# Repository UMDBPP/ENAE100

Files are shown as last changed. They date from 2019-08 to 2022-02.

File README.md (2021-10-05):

# ENAE100
This repository is for the starter shields used in the ENAE100 Freshman Workshops during the fall semester

# Dependencies
* [OneWire](https://github.com/PaulStoffregen/OneWire) by Paul Stoffregen
* [DallasTemperature](https://github.com/milesburton/Arduino-Temperature-Control-Library) by Miles Burton
* [RTClib](https://github.com/adafruit/RTClib) by Adafruit

# Contents
## /Board
Gerbers and board files

## /Code/StarterShield
Working sample code for the board

# Notes/FAQ
1. SD Chip Select is Pin 10
2. LED is on pin 9

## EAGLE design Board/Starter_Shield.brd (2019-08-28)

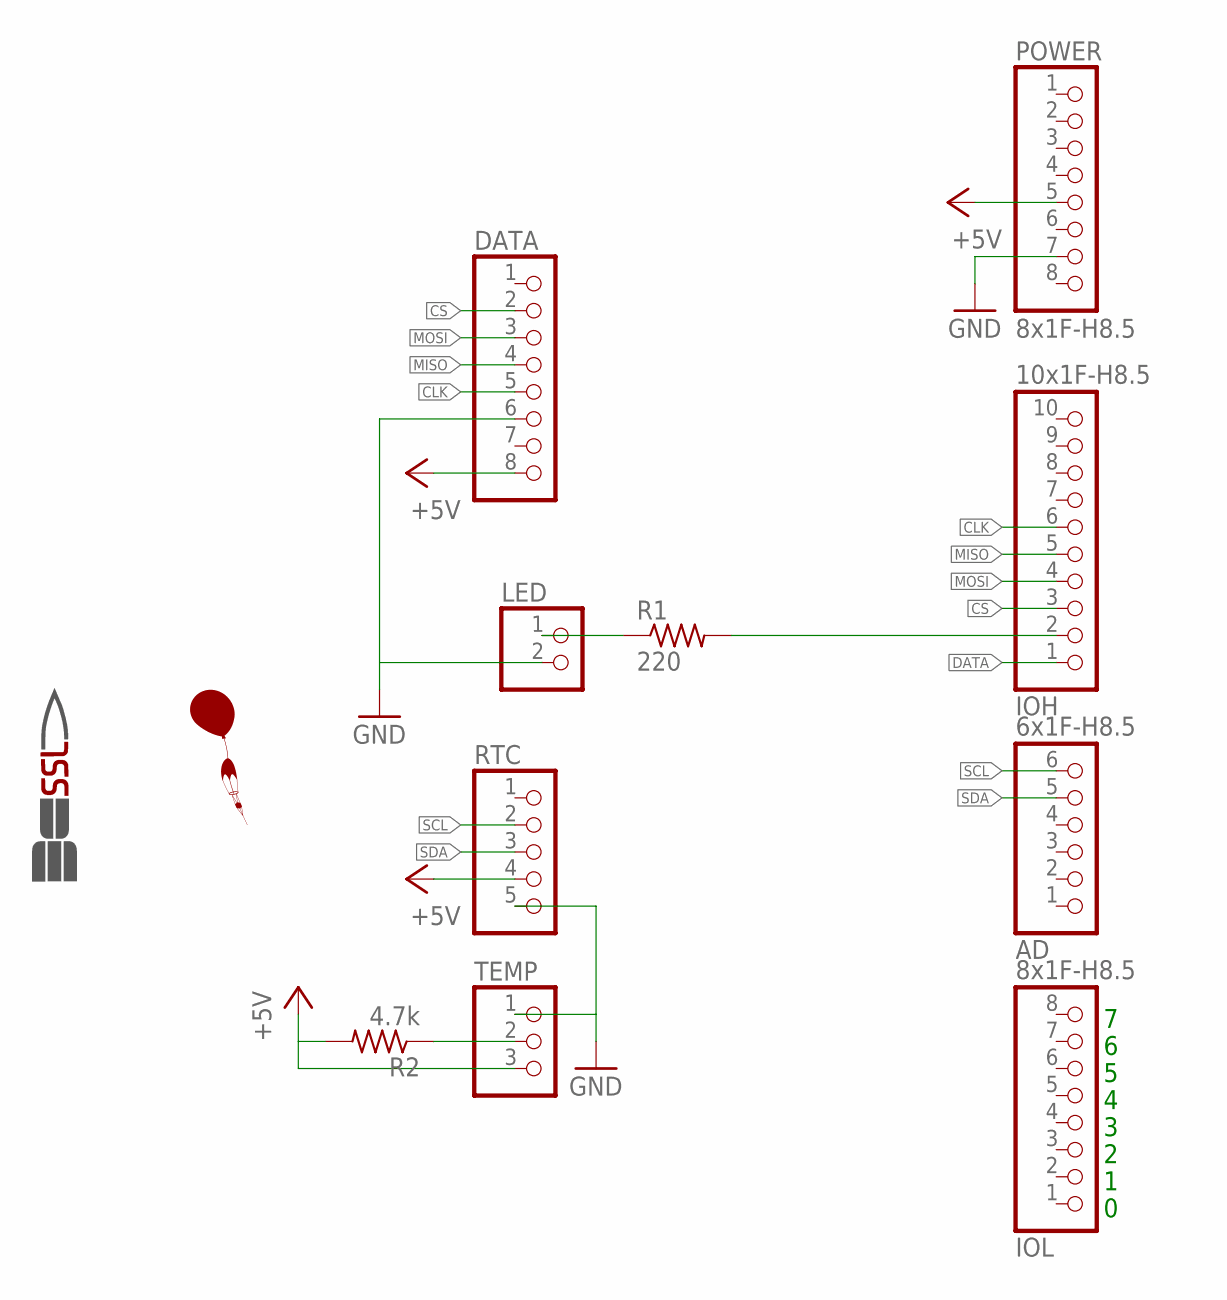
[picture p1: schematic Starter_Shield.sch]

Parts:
AD: 6x1F-H8.5; 1X06
DATA: PINHD-1X8; 1X08
IMAG1: SSL.53IN; SSL_.53IN
IOH: 10x1F-H8.5; 1X10
IOL: 8x1F-H8.5; 1X08
LED: PINHD-1X2; 1X02
POWER: 8x1F-H8.5; 1X08
R1: 220; 0207/10
R2: 4.7k; 0207/10
RTC: PINHD-1X5; 1X05
TEMP: PINHD-1X3; 1X03
U$1: BALLOON

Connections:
+5V: DATA.8, POWER.5, R2.2, RTC.4, TEMP.3
CLK: DATA.5, IOH.6
CS: DATA.2, IOH.3
DATA: IOH.1, R2.1, TEMP.2
GND: DATA.6, LED.2, POWER.7, RTC.5, TEMP.1
MISO: DATA.4, IOH.5
MOSI: DATA.3, IOH.4
unnamed: LED.1, R1.1
unnamed: IOH.2, R1.2
SCL: AD.6, RTC.2
SDA: AD.5, RTC.3

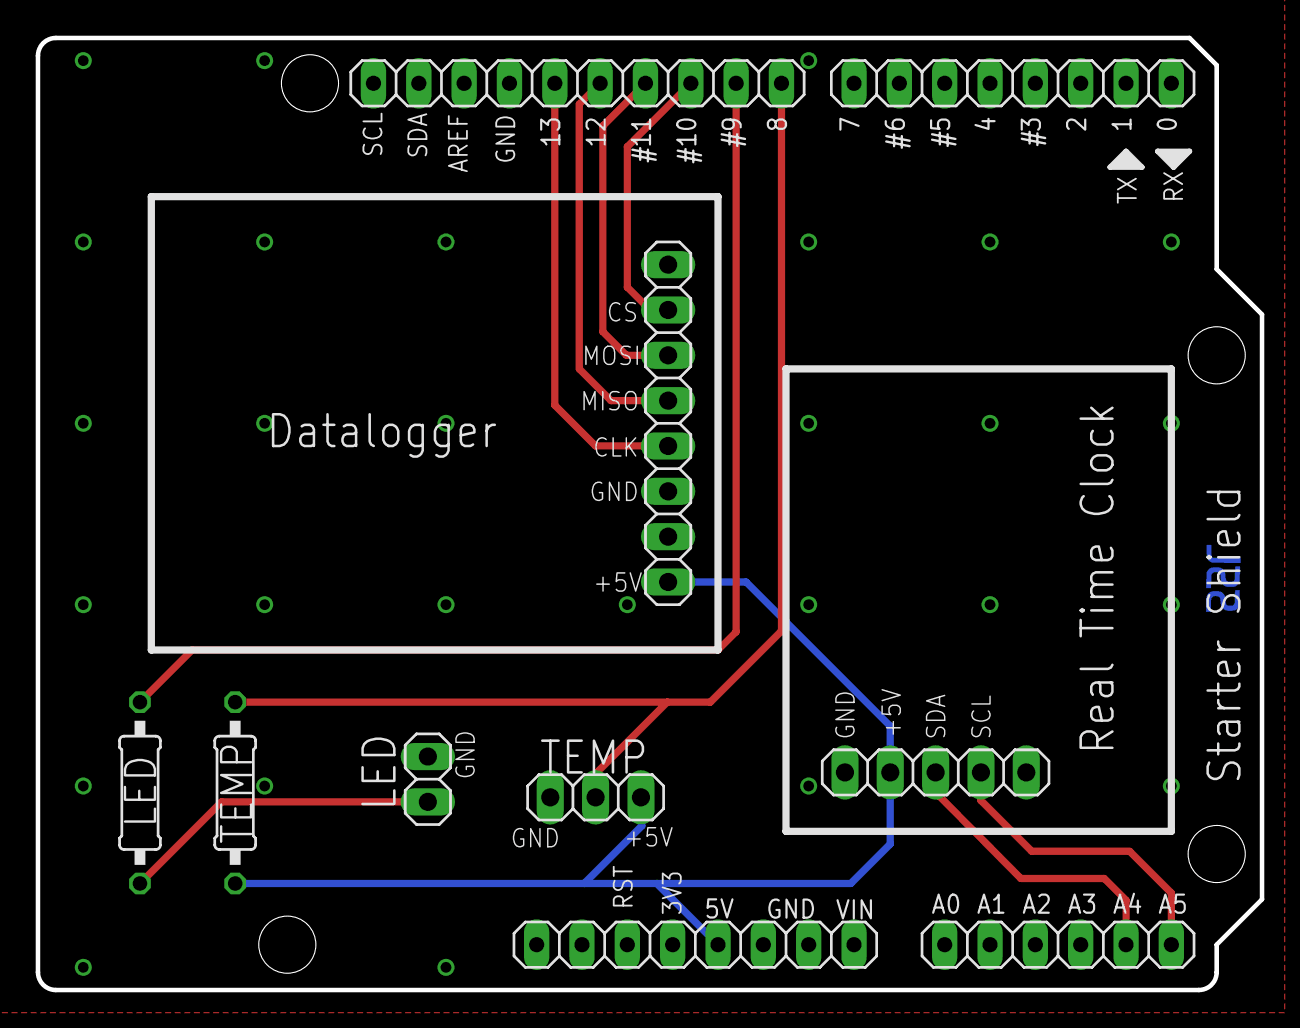
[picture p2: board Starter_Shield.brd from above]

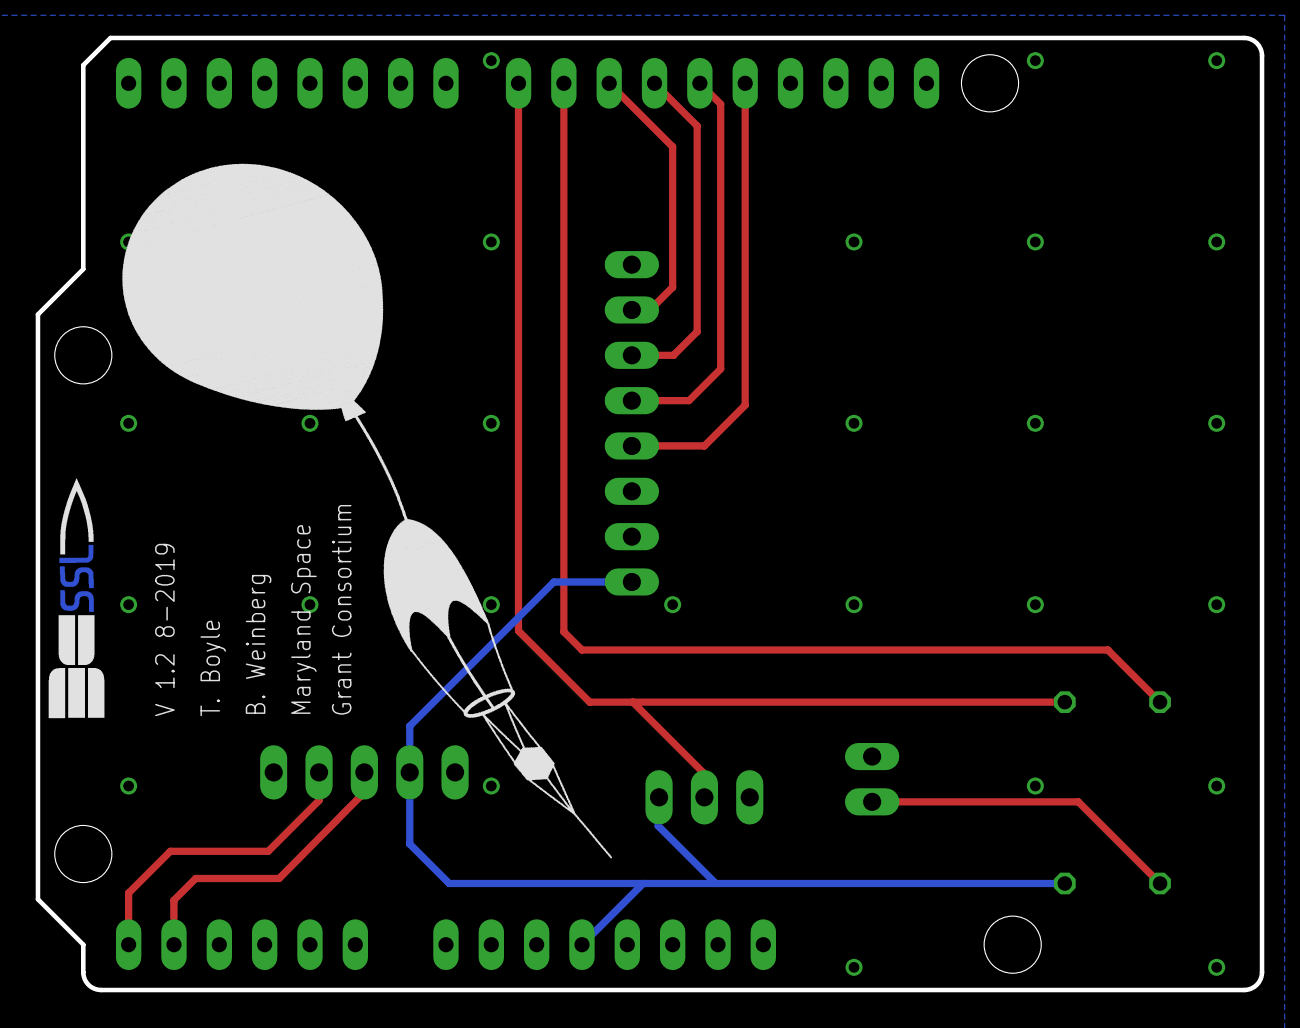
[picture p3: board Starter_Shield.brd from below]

Board: 2 copper layers, 68.6 x 53.3 mm, 12 parts (2 on the bottom side), 11 nets.

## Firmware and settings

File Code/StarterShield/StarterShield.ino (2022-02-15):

/* This code is designed for the Starter Shields for the NearSpace ENAE100 Workshops
 *  Sensors incorperated on the shield
 *    DS18B22
 *    SD Logger (Adafruit)
 *    DS1307 (Adafruit)
 *  Code originally  written and commented by Tyler Boyle, September 2017
 *  Code modified by Blaire Weinberg, Fall 2019
 *  Code modified by Michael Kalin, Fall 2021
 */

// Libraries
#include <SPI.h>
#include <SD.h>
#include <OneWire.h> //install OneWire by Paul Stoffregen
#include <DallasTemperature.h> //install DallasTemperature by Miles Burton
#include <RTClib.h> //install RTClib by Adafruit

// Define constants which specify which pins we are using on our Arduino
#define ONE_WIRE_BUS 8 // Temperature probe data line
#define CS 10 // Chip Select on SD logger
#define ledPin 9 // LED

// Create the objects - what the actual sensor returns data values to
OneWire oneWire(ONE_WIRE_BUS);
DallasTemperature temp(&oneWire);
RTC_DS1307 rtc; //make sure this RTC object matches the RTC you are using! (some people might be using a PCF8523)

void setup() {
  Serial.begin(9600);

  // Make sure the logger is hooked up. If it's not nothing will run after this statement
  Serial.print("Initializing SD card...");

  if (!SD.begin(CS)) {
    Serial.println(F("Card failed, or not present"));
  }
  else {
    Serial.println(F("card initialized."));
  }

  // Initialize the sensors and get them to begin
  temp.begin();
  rtc.begin();
  
  //Comment out any RTC adjust lines and upload your code again after you set the RTC for the first time! Otherwise your RTC will reset every time it is powered on!
  rtc.adjust(DateTime(F(__DATE__), F(__TIME__))); // Automatically set the real-time clock, when to resetting the time of your RTC make sure to remove its battery
  // rtc.adjust(DateTime(2014, 1, 21, 3, 0, 0)); // Manually set the real-time clock

  pinMode(ledPin, OUTPUT); // Declare LED as an output pin
}

void loop() {
  // Call the sensors and have them return their data to the objects
  temp.requestTemperatures();
  DateTime now = rtc.now();

  // Assigning the values from the sensors to variables on the Arduino
  float temperature = temp.getTempCByIndex(0);

  //Store the current time in variables that we will be able to easily call upon later
  int day = now.day(), month = now.month(), year = now.year(), hour = now.hour(), minute = now.minute(), second = now.second();

  // To write to a file with this SD logger, you must first open the file
  File dataFile = SD.open("datalog.txt", FILE_WRITE);

  // If the file is available (meaning that it could open the file from the SD card), write to it:
  if (dataFile) {
    if(month < 10)
      dataFile.print(F("0"));
    dataFile.print(month);
    dataFile.print(F("/")); // Since we are printing single characters (data type of char) we could use '' instead of "", but for simplicity we will stick with double quotes
    if(day < 10) // Our RTC returns the time as an int, which means it wont have leading zeros when we print it, we add them in so our formatting stays consistant
      dataFile.print(F("0"));
    dataFile.print(day);
    dataFile.print(F("/"));
    dataFile.print(year);
    dataFile.print(F(" "));
    if(hour < 10)
      dataFile.print(F("0"));
    dataFile.print(hour);
    dataFile.print(F(":"));
    if(minute < 10)
      dataFile.print(F("0"));
    dataFile.print(minute);
    dataFile.print(F(":"));
    if(second < 10)
      dataFile.print(F("0"));
    dataFile.print(second);
    dataFile.print(F(", ")); // End each section of data with a comma, so our output is in the comma-separated-value (.csv) format
    
    dataFile.print(temperature); 
    // Each line in our datafile now has two entries, the first entry represents the time and the second entry represents the temperature at that time
    // When we attach more sensors to our Arduino, we can uncomment the line below to add another comma, and then print the data from the sensor
    // For each new piece of data you want to print, simply add a comma at the end of the previous data entry
    // dataFile.print(F(", "));
    
    dataFile.println(); // End each data take (row of data) with a new line
    
    dataFile.close(); //It is good practice to close the datafile when you are done using it, we will open it up again when we loop back to this section of the code
  }
  
  // If the file isn't open, pop up an error:
  else {
    Serial.println(F("error opening datalog.txt"));
  }

  // Print to your computer too, if its connected
  //The code below is the same code as above, except we are using Serial.print() to print to our computer instead of dataFile.print() which prints to the datafile
  if(Serial) {
    if(month < 10)
      Serial.print(F("0"));
    Serial.print(month);
    Serial.print(F("/"));
    if(day < 10)
      Serial.print(F("0"));
    Serial.print(day);
    Serial.print(F("/"));
    Serial.print(year);
    Serial.print(F(" "));
    if(hour < 10)
      Serial.print(F("0"));
    Serial.print(hour);
    Serial.print(F(":"));
    if(minute < 10)
      Serial.print(F("0"));
    Serial.print(minute);
    Serial.print(F(":"));
    if(second < 10)
      Serial.print(F("0"));
    Serial.print(second);
    Serial.print(F(", ")); 

    Serial.print(temperature); 
    //Serial.print(F(", "));

    Serial.println();
  }

  digitalWrite(ledPin, HIGH); // turn on the LED, this lets us know our code is running!
  delay(1000);
  
  digitalWrite(ledPin, LOW); // turn off the LED
  delay(1000);
}

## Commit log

2019-01-03 readme and board files
    [Starter_Shield.brd, Starter_Shield.sch]
2019-08-28 updated gnd on the datalogger to the right pin - V1.2 now
    [Starter_Shield.brd, Starter_Shield.sch]
2021-10-05 added a suggestion for freshman to create a print_time() function if they are feeling ambitious
2021-10-12 fixed bug, changed single quotes to double quotes
    [StarterShield.ino]
